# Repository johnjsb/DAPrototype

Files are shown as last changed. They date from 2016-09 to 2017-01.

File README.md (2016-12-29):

<div class="file">
  <div class="file-header">
  <div class="file-actions">

        <a class="btn-octicon tooltipped tooltipped-nw"
           href="https://windows.github.com"
           aria-label="Open this file in GitHub Desktop"
           data-ga-click="Repository, open with desktop, type:windows">
            <svg aria-hidden="true" class="octicon octicon-device-desktop" height="16" version="1.1" viewBox="0 0 16 16" width="16"><path fill-rule="evenodd" d="M15 2H1c-.55 0-1 .45-1 1v9c0 .55.45 1 1 1h5.34c-.25.61-.86 1.39-2.34 2h8c-1.48-.61-2.09-1.39-2.34-2H15c.55 0 1-.45 1-1V3c0-.55-.45-1-1-1zm0 9H1V3h14v8z"/></svg>
        </a>

        <!-- '"` --><!-- </textarea></xmp> --></option></form><form accept-charset="UTF-8" action="/nategreco/DAPrototype/edit/master/README.md" class="inline-form js-update-url-with-hash" data-form-nonce="98edccfe8496e23db9dd6daac1cc21b22fe630b1" method="post"><div style="margin:0;padding:0;display:inline"><input name="utf8" type="hidden" value="&#x2713;" /><input name="authenticity_token" type="hidden" value="Xxg+MZ2gaWbK/x79SvOasrFMR/OtOR6YhneYzXq2UvHyrXHXdxic8k2Q9TFyRKGyG20oO6GQx6e75jDCMJZNnA==" /></div>
          <button class="btn-octicon tooltipped tooltipped-nw" type="submit"
            aria-label="Fork this project and edit the file" data-hotkey="e" data-disable-with>
            <svg aria-hidden="true" class="octicon octicon-pencil" height="16" version="1.1" viewBox="0 0 14 16" width="14"><path fill-rule="evenodd" d="M0 12v3h3l8-8-3-3-8 8zm3 2H1v-2h1v1h1v1zm10.3-9.3L12 6 9 3l1.3-1.3a.996.996 0 0 1 1.41 0l1.59 1.59c.39.39.39 1.02 0 1.41z"/></svg>
          </button>
</form>        <!-- '"` --><!-- </textarea></xmp> --></option></form><form accept-charset="UTF-8" action="/nategreco/DAPrototype/delete/master/README.md" class="inline-form" data-form-nonce="98edccfe8496e23db9dd6daac1cc21b22fe630b1" method="post"><div style="margin:0;padding:0;display:inline"><input name="utf8" type="hidden" value="&#x2713;" /><input name="authenticity_token" type="hidden" value="XiElkEE2MjGLgCf0HjS3MaQ2nTFOKo5D3A2KYL0wVELzlGp2q47HpQzvzDgmg4wxDhfy+UKDV3zhnCJv9xBLLw==" /></div>
          <button class="btn-octicon btn-octicon-danger tooltipped tooltipped-nw" type="submit"
            aria-label="Fork this project and delete the file" data-disable-with>
            <svg aria-hidden="true" class="octicon octicon-trashcan" height="16" version="1.1" viewBox="0 0 12 16" width="12"><path fill-rule="evenodd" d="M11 2H9c0-.55-.45-1-1-1H5c-.55 0-1 .45-1 1H2c-.55 0-1 .45-1 1v1c0 .55.45 1 1 1v9c0 .55.45 1 1 1h7c.55 0 1-.45 1-1V5c.55 0 1-.45 1-1V3c0-.55-.45-1-1-1zm-1 12H3V5h1v8h1V5h1v8h1V5h1v8h1V5h1v9zm1-10H2V3h9v1z"/></svg>
          </button>
</form>  </div>

</div>

  <div id="readme" class="readme blob instapaper_body">
    <article class="markdown-body entry-content" itemprop="text"><h1><a id="user-content-product-name" class="anchor" href="#product-name" aria-hidden="true"><svg aria-hidden="true" class="octicon octicon-link" height="16" version="1.1" viewBox="0 0 16 16" width="16"><path fill-rule="evenodd" d="M4 9h1v1H4c-1.5 0-3-1.69-3-3.5S2.55 3 4 3h4c1.45 0 3 1.69 3 3.5 0 1.41-.91 2.72-2 3.25V8.59c.58-.45 1-1.27 1-2.09C10 5.22 8.98 4 8 4H4c-.98 0-2 1.22-2 2.5S3 9 4 9zm9-3h-1v1h1c1 0 2 1.22 2 2.5S13.98 12 13 12H9c-.98 0-2-1.22-2-2.5 0-.83.42-1.64 1-2.09V6.25c-1.09.53-2 1.84-2 3.25C6 11.31 7.55 13 9 13h4c1.45 0 3-1.69 3-3.5S14.5 6 13 6z"></path></svg></a>Raspberry Pi Driver Assist</h1>

<blockquote>
<p>A standalone driver assist unit based on Raspberry Pi hardware and OpenCV libraries</p>
</blockquote>

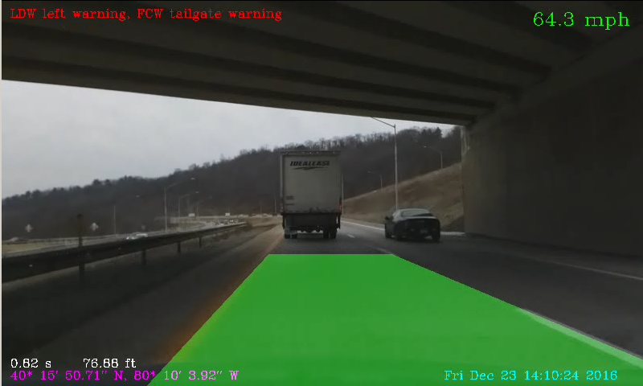
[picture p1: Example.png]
<p></p>
<p><a href="https://youtu.be/WRAR0lgYsj8">Daytime driving conditions</a></p>
<p><a href="https://youtu.be/zDFjwTFDbJ0">Nighttime driving conditions</a></p>
<p><a href="https://youtu.be/yc1ApW6gV3I">Rainy driving conditions</a></p>

<blockquote>
<p>This project is an attempt to create a standalone, windshield mounted driver assist unit with the following functionality:
<ul>
<li>LDW (Lane Departure Warning)</li>
<li>FCW (Forward Collision Warning)</li>
<li>Tailgate warning</li>
<li>Driver pull-ahead warning</li>
<li>Dashcam functionality (with GPS & timestamp overlay)</li>
</ul>
</p>
</blockquote>

<h2><a id="user-content-installation" class="anchor" href="#installation" aria-hidden="true"><svg aria-hidden="true" class="octicon octicon-link" height="16" version="1.1" viewBox="0 0 16 16" width="16"><path fill-rule="evenodd" d="M4 9h1v1H4c-1.5 0-3-1.69-3-3.5S2.55 3 4 3h4c1.45 0 3 1.69 3 3.5 0 1.41-.91 2.72-2 3.25V8.59c.58-.45 1-1.27 1-2.09C10 5.22 8.98 4 8 4H4c-.98 0-2 1.22-2 2.5S3 9 4 9zm9-3h-1v1h1c1 0 2 1.22 2 2.5S13.98 12 13 12H9c-.98 0-2-1.22-2-2.5 0-.83.42-1.64 1-2.09V6.25c-1.09.53-2 1.84-2 3.25C6 11.31 7.55 13 9 13h4c1.45 0 3-1.69 3-3.5S14.5 6 13 6z"></path></svg></a>Installation</h2>

<p>Debian (Jessie):</p>
<div class="highlight highlight-source-shell">
<pre>todo</pre>
</div>

<h2><a id="user-content-usage-example" class="anchor" href="#usage-example" aria-hidden="true"><svg aria-hidden="true" class="octicon octicon-link" height="16" version="1.1" viewBox="0 0 16 16" width="16"><path fill-rule="evenodd" d="M4 9h1v1H4c-1.5 0-3-1.69-3-3.5S2.55 3 4 3h4c1.45 0 3 1.69 3 3.5 0 1.41-.91 2.72-2 3.25V8.59c.58-.45 1-1.27 1-2.09C10 5.22 8.98 4 8 4H4c-.98 0-2 1.22-2 2.5S3 9 4 9zm9-3h-1v1h1c1 0 2 1.22 2 2.5S13.98 12 13 12H9c-.98 0-2-1.22-2-2.5 0-.83.42-1.64 1-2.09V6.25c-1.09.53-2 1.84-2 3.25C6 11.31 7.55 13 9 13h4c1.45 0 3-1.69 3-3.5S14.5 6 13 6z"></path></svg></a>Hardware</h2>

<p>Part List:</p>
<div class="highlight highlight-source-shell">
<ul>
<li>Raspberry Pi v3</li>
<li>8gb (or greater) class 10 SD card</li>
<li>Rasbperry Pi v2.1 camera with cable</li>
<li>LidarLite (v3) LIDAR rangefinder</li>
<li>Adafruit Ultimate GPS</li>
<li>GPS antenna and adapter</li>
<li>5" HDMI 800x480 screen</li>
<li>Flexible HDMI elbow</li>
<li>Buzzer</li>
<li>Female DC barrel jack connector</li>
<li>Cigarette adapter with male DC barrel connector</li>
<li>68000000uF 16V capacitor</li>
<li>Power LED</li>
<li>3D printed or other fabricated housing</li>
<li>Custom made breadboard</li>
<ul>
<li>DC:DC buck poswer supply, 12V to 5V</li>
<li>40-pin female header</li>
<li>12V relay</li>
<li>Various resistors, diodes, male and female header pins</li>
</ul>
</ul>
</div>

<h2><a id="user-content-development-setup" class="anchor" href="#development-setup" aria-hidden="true"><svg aria-hidden="true" class="octicon octicon-link" height="16" version="1.1" viewBox="0 0 16 16" width="16"><path fill-rule="evenodd" d="M4 9h1v1H4c-1.5 0-3-1.69-3-3.5S2.55 3 4 3h4c1.45 0 3 1.69 3 3.5 0 1.41-.91 2.72-2 3.25V8.59c.58-.45 1-1.27 1-2.09C10 5.22 8.98 4 8 4H4c-.98 0-2 1.22-2 2.5S3 9 4 9zm9-3h-1v1h1c1 0 2 1.22 2 2.5S13.98 12 13 12H9c-.98 0-2-1.22-2-2.5 0-.83.42-1.64 1-2.09V6.25c-1.09.53-2 1.84-2 3.25C6 11.31 7.55 13 9 13h4c1.45 0 3-1.69 3-3.5S14.5 6 13 6z"></path></svg></a>Third party libraries</h2>

<p>Requirements:</p>
<div class="highlight highlight-source-shell">
<ul>
<li>OpenCv 3.1.0</li>
<li>Raspicam 0.1.3</li>
<li>WiringPi 2.29</li>
</ul>
</div>

<h2><a id="user-content-release-history" class="anchor" href="#release-history" aria-hidden="true"><svg aria-hidden="true" class="octicon octicon-link" height="16" version="1.1" viewBox="0 0 16 16" width="16"><path fill-rule="evenodd" d="M4 9h1v1H4c-1.5 0-3-1.69-3-3.5S2.55 3 4 3h4c1.45 0 3 1.69 3 3.5 0 1.41-.91 2.72-2 3.25V8.59c.58-.45 1-1.27 1-2.09C10 5.22 8.98 4 8 4H4c-.98 0-2 1.22-2 2.5S3 9 4 9zm9-3h-1v1h1c1 0 2 1.22 2 2.5S13.98 12 13 12H9c-.98 0-2-1.22-2-2.5 0-.83.42-1.64 1-2.09V6.25c-1.09.53-2 1.84-2 3.25C6 11.31 7.55 13 9 13h4c1.45 0 3-1.69 3-3.5S14.5 6 13 6z"></path></svg></a>Release History</h2>

<ul>
<li>0.0.1

<ul>
<li>Work in progress</li>
</ul></li>
</ul>

<h2><a id="user-content-meta" class="anchor" href="#meta" aria-hidden="true"><svg aria-hidden="true" class="octicon octicon-link" height="16" version="1.1" viewBox="0 0 16 16" width="16"><path fill-rule="evenodd" d="M4 9h1v1H4c-1.5 0-3-1.69-3-3.5S2.55 3 4 3h4c1.45 0 3 1.69 3 3.5 0 1.41-.91 2.72-2 3.25V8.59c.58-.45 1-1.27 1-2.09C10 5.22 8.98 4 8 4H4c-.98 0-2 1.22-2 2.5S3 9 4 9zm9-3h-1v1h1c1 0 2 1.22 2 2.5S13.98 12 13 12H9c-.98 0-2-1.22-2-2.5 0-.83.42-1.64 1-2.09V6.25c-1.09.53-2 1.84-2 3.25C6 11.31 7.55 13 9 13h4c1.45 0 3-1.69 3-3.5S14.5 6 13 6z"></path></svg></a>Meta</h2>

<p>Nathan Greco – <a href="https://www.linkedin.com/in/nathan-greco-8050b210">LinkedIn</a> – <a href="mailto:nathan.greco@gmail.com">Nathan.Greco@gmail.com</a></p>

<p>Distributed under the GNU GPL 3.0 license. See <code>LICENSE</code> for more information.</p>

<p><a href="https://github.com/nategreco/">https://github.com/nategreco/github-link</a></p>
</article>
  </div>

</div>

<div id="jump-to-line" style="display:none">
  <!-- '"` --><!-- </textarea></xmp> --></option></form><form accept-charset="UTF-8" action="" class="js-jump-to-line-form" method="get"><div style="margin:0;padding:0;display:inline"><input name="utf8" type="hidden" value="&#x2713;" /></div>
    <input class="form-control linejump-input js-jump-to-line-field" type="text" placeholder="Jump to line&hellip;" aria-label="Jump to line" autofocus>
</form></div>

  </div>
  
</div>

  <div class="site-footer" role="contentinfo">
    <ul class="site-footer-links float-right">
        <li><a href="https://github.com/contact" data-ga-click="Footer, go to contact, text:contact">Contact GitHub</a></li>
      <li><a href="https://developer.github.com" data-ga-click="Footer, go to api, text:api">API</a></li>
      <li><a href="https://training.github.com" data-ga-click="Footer, go to training, text:training">Training</a></li>
      <li><a href="https://shop.github.com" data-ga-click="Footer, go to shop, text:shop">Shop</a></li>
        <li><a href="https://github.com/blog" data-ga-click="Footer, go to blog, text:blog">Blog</a></li>
        <li><a href="https://github.com/about" data-ga-click="Footer, go to about, text:about">About</a></li>

 </a>
    <ul class="site-footer-links">
      <li>&copy; 2016 <span title="0.09722s from github-fe-1e914f7.cp1-iad.github.net">GitHub</span>, Inc.</li>
        <li><a href="https://github.com/site/terms" data-ga-click="Footer, go to terms, text:terms">Terms</a></li>
        <li><a href="https://github.com/site/privacy" data-ga-click="Footer, go to privacy, text:privacy">Privacy</a></li>
        <li><a href="https://github.com/security" data-ga-click="Footer, go to security, text:security">Security</a></li>
        <li><a href="https://status.github.com/" data-ga-click="Footer, go to status, text:status">Status</a></li>
        <li><a href="https://help.github.com" data-ga-click="Footer, go to help, text:help">Help</a></li>
    </ul>
  </div>
</div>

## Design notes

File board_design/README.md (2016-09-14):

This folder will the circuit board design for for the driver assist device.

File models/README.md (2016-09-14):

This folder will the 3D models for the housing of the driver assist device.

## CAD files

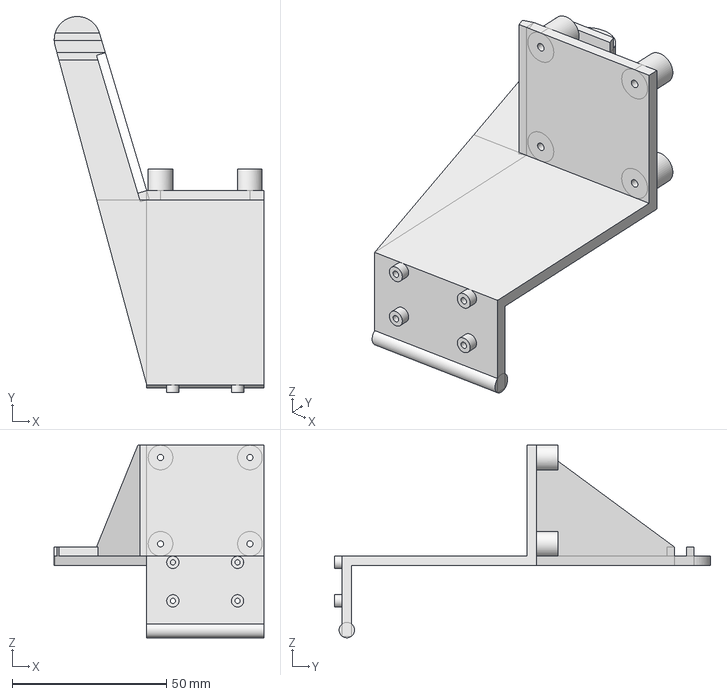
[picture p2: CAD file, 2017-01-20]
models/DAPrototypeInset.FCStd
68.0 x 122.0 x 62.5 mm

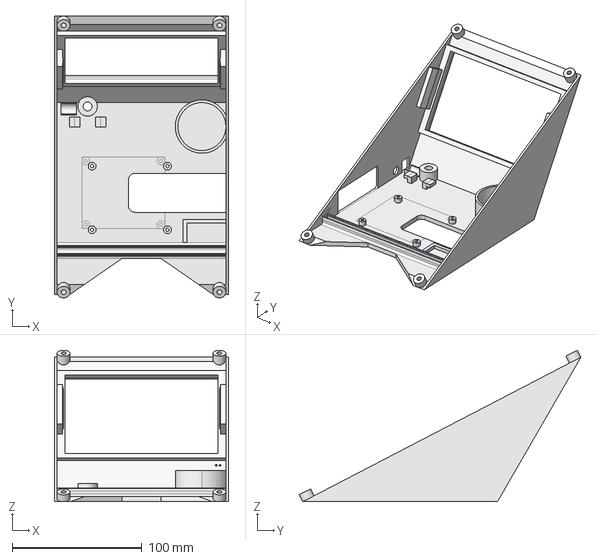
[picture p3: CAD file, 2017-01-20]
models/DAPrototypeHolder.FCStd
134.0 x 217.1 x 116.7 mm

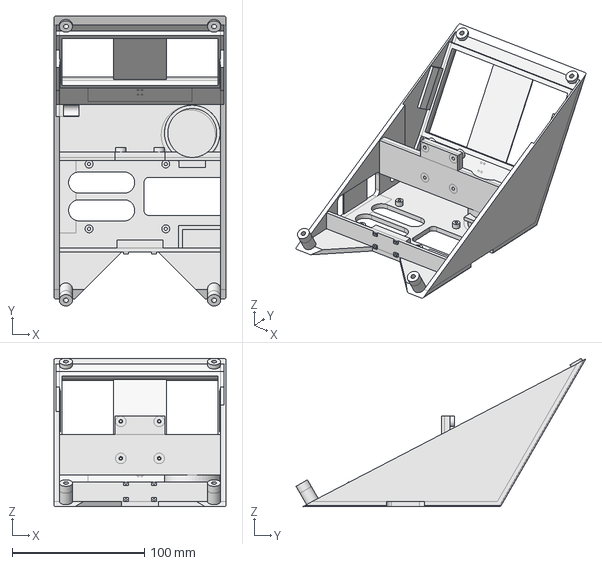
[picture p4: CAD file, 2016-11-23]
models/DAPrototypeV5.FCStd
130.0 x 219.3 x 112.2 mm

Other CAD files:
models/DAPrototypeHolder.stl
models/DAPrototypeInset.stl
models/DAprototypeV5.stl

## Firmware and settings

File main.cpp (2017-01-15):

/******************************************************************************************
  Date:    12.08.2016
  Author:  Nathan Greco (Nathan.Greco@gmail.com)

  Project:
      DAPrototype: Driver Assist Prototype
	  http://github.com/NateGreco/DAPrototype.git

  Description:
      This project is an attempt to create a standalone, windshield mounted driver assist
      unit with the following functionality:
		  - LDW (Lane Departure Warning)
		  - FCW (Forward Collision Warning)
		  - Tailgate warning
		  - Driver pull-ahead warning
		  - Dashcam functionality (with GPS & timestamp overlay)

  Target Hardware:
      - Raspberry Pi (v3)
	  - RPi (v2.1) 8MP camera
	  - LidarLite (v3) LIDAR rangefinder
      - Adafruit Ultimate GPS
      - HDMI screen (800x480)
	  - Custom built HAT w/ power loss GPIO and capacitors to delay power off

  Target Software platform:
      Debian disto (DietPi) running LDXE, with below libraries installed

  3rd Party Libraries:
      - OpenCV 3.1.0		-> http://www.opencv.org *Compiled with OpenGL support
      - Raspicam 0.1.3		-> http://www.uco.es/investiga/grupos/ava/node/40
	  - WiringPi 2.29		-> http://wiringpi.com/
	  
  License:
	  This software is licensed under GNU GPL v3.0

  History:
      Date         Author      Description
-------------------------------------------------------------------------------------------
      12.08.2016   N. Greco    Initial creation
      07.09.2016   N. Greco    GIT repository created
	  04.10.2016   N. Greco    Compiled and tested on raspberry pi hardware
******************************************************************************************/


//Standard libraries
#include <iostream>
#include <algorithm>
#include <fstream>
#include <string>
#include <thread>
#include <cstdlib>
#include <mutex>
#include <atomic>

//3rd party libraries
#include "opencv2/opencv.hpp"
#include <libgpsmm.h>

//DAPrototype source files
#include "display_handler.h"
#include "gpio_handler.h"
#include "gps_polling.h"
#include "image_capturer.h"
#include "image_editor.h"
#include "image_processor.h"
#include "lane_detect_processor.h"
#include "lidar_polling.h"
#include "pace_setter_class.h"
#include "process_values_class.h"
#include "video_writer.h"
#include "xml_reader.h"
#include "fcw_tracker_class.h"

void PrintHeader ()
{
	time_t t = time(0);
    struct tm * now = localtime( & t );
    std::cout << '\n';
    std::cout << "Program launched at: ";
    std::cout << (now->tm_year + 1900) << '-' 
			  << (now->tm_mon + 1) << '-'
			  <<  now->tm_mday
			  << '\n' << '\n';
}

int main()
{
	std::cout << "Program launched, starting log file..." << '\n';
	//Quick and dirty log file
	std::ofstream out("/log.txt", std::ios_base::app | std::ios_base::out);
	std::streambuf *coutbuf = std::cout.rdbuf();
	std::cout.rdbuf(out.rdbuf());
	
	//Create log header
	PrintHeader();
	
    //Check XML Properties
	if (settings::kreadsuccess < 0) {
        std::cout << "XML reading failed, using defaults." << '\n';
    } else {
        std::cout << "XML reading successful!" << '\n';
    }

	//Create shared resources
	std::atomic<bool> exitsignal{ false };
    cv::Mat captureimage;
	std::mutex capturemutex;
	cv::Mat displayimage;
	std::mutex displaymutex;
	ProcessValues processvalues;
	
	//Start threads

	//Start image capture thread
    std::thread t_imagecapture( CaptureImageThread,
	                            &captureimage,
								&capturemutex,
								&exitsignal );
	//Start image processor thread
    std::thread t_imageprocessor( ProcessImageThread,
								  &captureimage,
								  &capturemutex,
								  &processvalues,
								  &exitsignal );
	//Start display thread
	std::thread t_displayupdate( DisplayUpdateThread,
								 &displayimage,
								 &displaymutex,
								 &exitsignal );
	//Start image editor thread
    std::thread t_imeageeditor( ImageEditorThread,
								&captureimage,
								&capturemutex,
								&displayimage,
								&displaymutex,
								&processvalues,
								&exitsignal );
	//Start video writer thread
    std::thread t_videowriter( VideoWriterThread,
							   &captureimage,
							   &capturemutex,
							   &displayimage,
							   &displaymutex,
							   &exitsignal );

    //Set pace setter class!
	int pollrate{ std::max(std::max(settings::comm::kpollrategps,
									settings::comm::kpollratelidar),
						   settings::comm::kpollrategpio) };
	int bufferflushrate { pollrate * 10};	//Every 10 seconds
	int gpspollinterval{ pollrate / settings::comm::kpollrategps };
	int gpiopollinterval{ pollrate / settings::comm::kpollrategpio };
	int fcwpollinterval{ pollrate / settings::comm::kpollratelidar };
	PaceSetter mypacesetter( pollrate, "Main" );
	
	//Setup polling

	//GPIO
	bool gpiopoll{ false };
	if ( settings::gpio::kenabled ) {
		try {
			gpiopoll = GpioHandlerSetup();
		} catch ( const std::exception& ex ) {
			std::cout << "GPIO handler setup threw exception: "<< ex.what() << '\n';
			gpiopoll = false;
		} catch ( const std::string& str ) {
			std::cout << "GPIO handler setup threw exception: "<< str << '\n';
			gpiopoll = false;
		} catch (...) {
			std::cout << "GPIO handler setup threw exception of unknown type!" << '\n';
			gpiopoll = false;
		}
	}
	//GPS
	gpsmm* gpsrecv{ NULL };
	bool gpspoll{ false };
	bool timeset{ false };
	if ( settings::gps::kenabled ) {
		try {
			gpsrecv = new gpsmm("localhost", DEFAULT_GPSD_PORT);
			gpspoll = GpsPollingSetup( gpsrecv );
		} catch ( const std::exception& ex ) {
			std::cout << "GPS polling setup threw exception: "<< ex.what() << '\n';
			gpspoll = false;
		} catch ( const std::string& str ) {
			std::cout << "GPS polling setup threw exception: "<< str << '\n';
			gpspoll = false;
		} catch (...) {
			std::cout << "GPS polling setup threw exception of unknown type!" << '\n';
			gpspoll = false;
		}
	} else {
		gpsrecv = NULL;
	}
	//FCW
	FcwTracker* fcwtracker{ NULL };
	bool fcwpoll{ false };
	int dacmodule{ -1 };
	if ( settings::fcw::kenabled ) {
		try {
			fcwtracker = new FcwTracker( settings::fcw::ksamplestoaverage );
			dacmodule = LidarPollingSetup();
			if ( dacmodule >= 0 ) fcwpoll = true;
		} catch ( const std::exception& ex ) {
			std::cout << "FCW setup threw exception: "<< ex.what() << '\n';
			fcwpoll = false;
		} catch ( const std::string& str ) {
			std::cout << "FCW setup threw exception: "<< str << '\n';
			fcwpoll = false;
		} catch (...) {
			std::cout << "FCW setup threw exception of unknown type!" << '\n';
			fcwpoll = false;
		}
	} else {
		fcwtracker = NULL;
	}
    
	//Loop
	int i{ 0 };
	do {
		//Increment
		i++;
		//Flush cout buffer every second
		if ( i % bufferflushrate == 0 ) std::cout << std::flush;
		if ( (gpspoll) &&
			 (i % gpspollinterval == 0) ) GpsPolling( processvalues,
													  gpsrecv,
													  timeset );
		if ( (gpiopoll) &&
			 (i % gpiopollinterval == 0) ) GpioHandler( processvalues,
														exitsignal );
		if ( (fcwpoll) &&
			 (i % fcwpollinterval == 0) ) LidarPolling( processvalues,
														dacmodule,
													    fcwtracker );

		//Set Pace
		mypacesetter.SetPace();
	} while( !exitsignal );
	
	//Cleanup variables
	delete gpsrecv;
	gpsrecv = NULL;
	delete fcwtracker;
	fcwtracker = NULL;

    //Handle all the threads
	t_videowriter.join();
	t_imageprocessor.join();
	t_imeageeditor.join();
	t_imagecapture.join();
	t_displayupdate.join();

	//Flush buffer and close file
	std::cout << std::flush;
	std::cout.rdbuf(coutbuf);
	std::cout << "Program exited gracefully!"  << '\n';

    return 0;
}

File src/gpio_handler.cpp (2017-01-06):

/******************************************************************************************
  Date:    12.08.2016
  Author:  Nathan Greco (Nathan.Greco@gmail.com)

  Project:
      DAPrototype: Driver Assist Prototype
	  http://github.com/NateGreco/DAPrototype.git

  License:
	  This software is licensed under GNU GPL v3.0
	  
******************************************************************************************/
//Standard libraries
#include <iostream>
#include <atomic>
#include <stdlib.h>
#include <exception>
#include <string>

//3rd party libraries
#include <wiringPi.h>
#include <wiringPiI2C.h>

//Project libraries
#include "pace_setter_class.h"
#include "process_values_class.h"
#include "xml_reader.h"

//Preprocessor

//Physical pin numbers
#define BUZZERPIN 27
#define POWERINPUTPIN 4
#define POWEROUTPUTPIN 5
#define LEFTALARMPIN 17
#define LEFTWARNINGPIN 13
#define LEFTOKPIN 12
#define RIGHTALARMPIN 23
#define RIGHTWARNINGPIN 22
#define RIGHTOKPIN 18
#define FORWARDALARMPIN 26
#define FORWARDWARNINGPIN 25
#define FORWARDOKPIN 24
#define CENTERPIN 37

/*****************************************************************************************/
bool GpioHandlerSetup()
{
	//Setup GPIO pins
	wiringPiSetupGpio();
	pinMode(POWERINPUTPIN, INPUT); 
	pinMode(BUZZERPIN, OUTPUT);
	pinMode(LEFTALARMPIN, PWM_OUTPUT);
	pinMode(LEFTWARNINGPIN, PWM_OUTPUT);
	pinMode(LEFTOKPIN, PWM_OUTPUT);
	pinMode(RIGHTALARMPIN, PWM_OUTPUT);
	pinMode(RIGHTWARNINGPIN, PWM_OUTPUT);
	pinMode(RIGHTOKPIN, PWM_OUTPUT);
	pinMode(FORWARDALARMPIN, PWM_OUTPUT);
	pinMode(FORWARDWARNINGPIN, PWM_OUTPUT);
	pinMode(FORWARDOKPIN, PWM_OUTPUT);
	pinMode(CENTERPIN, OUTPUT);
	pinMode(POWEROUTPUTPIN, OUTPUT);
	digitalWrite(POWEROUTPUTPIN, 1);
	
	return true;
}

void GpioHandler( ProcessValues& processvalues,
				  std::atomic<bool>& exitsignal )
{
	try {
		//Create thread variables
		bool warning{ false };
		bool alarm{ false };
		int buzzerinterval{  settings::comm::kpollrategpio / 2  };	//500ms
		int blinkinterval{  settings::comm::kpollrategpio / 2  };	//500ms
		int buzzercount{ 0 };
		int blinkercount{ 0 };
		int inputfailcount{ 0 };
		
		//Check for Warnings
		if ( (processvalues.ldwstatus_ > LDW_RIGHT_DEVIATION_OK) ||
			 (processvalues.fcwstatus_ > FCW_ACTIVE) ||
			 (processvalues.gpsstatus_ > GPS_LOCK_LDW_ON) ) {
			warning = true;
		} else {
			warning = alarm = false;
		}
		//Check for Alarms
		if ( (processvalues.ldwstatus_ > LDW_RIGHT_DEVIATION_WARNING) ||
			 (processvalues.fcwstatus_ > FCW_TAILGATE_WARNING) ||
			 (processvalues.gpsstatus_ > GPS_SPEED_WARNING) ) {
			alarm = true;
		}

		//Shutdown logic on power loss
		if ( !digitalRead(POWERINPUTPIN) ) {
			exitsignal = true;
			std::cout << "Power loss detected, exiting!" << '\n';
			if ( settings::gpio::kautoshutdown ) {
				digitalWrite(POWEROUTPUTPIN, 0);
			}
			return;
		}

		//Set buzzer
		if ( alarm && settings::gen::kenbuzzer ) {
			digitalWrite(BUZZERPIN, 1);
		} else if ( !alarm && warning && settings::gen::kenbuzzer ) {
			buzzercount++;
			if ( buzzercount % buzzerinterval != 0) {
				//Do nothing
			} else if (digitalRead(BUZZERPIN)) {
				digitalWrite(BUZZERPIN, 1);
			} else {
				digitalWrite(BUZZERPIN, 0);
			}
		} else {
			digitalWrite(BUZZERPIN, 0);
			buzzercount = buzzerinterval - 1;
		}

		//Set center LED
		if ( (processvalues.ldwstatus_ >= LDW_INACTIVE) &&
			 (processvalues.fcwstatus_ >= FCW_ACTIVE) &&
			 (processvalues.gpsstatus_ > GPS_NO_LOCK) ) {
				digitalWrite(CENTERPIN, 1);
		} else if ( (processvalues.ldwstatus_ >= LDW_INACTIVE) &&
					(processvalues.fcwstatus_ >= FCW_ACTIVE) &&
					(processvalues.gpsstatus_ == GPS_INACTIVE) ) {
			blinkercount++;
			if ( blinkercount % blinkinterval != 0) {
				//Do nothing
			} else if (digitalRead(CENTERPIN)) {
				digitalWrite(CENTERPIN, 1);
			} else {
				digitalWrite(CENTERPIN, 0);
			}
			} else {
			digitalWrite(CENTERPIN, 0);
		}
	} catch ( const std::exception& ex ) {
		std::cout << "GPIO handler thread threw exception: "<< ex.what() << '\n';
	} catch ( const std::string& str ) {
		std::cout << "GPIO handler thread threw exception: "<< str << '\n';
	} catch (...) {
		std::cout << "GPIO handler thread threw exception of unknown type!" << '\n';
	}
	
	return;
}

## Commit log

2016-09-14 Added directories for models and circuit design
2016-09-14 Updated gpio and corrected mistake in gps
    [gpio_handler.cpp]
2016-09-14 Wrote PWM logic for LEDs
2016-09-14 Created driver pullahead warning
2016-09-16 Added comments to consider HoughLinesP instead of findContours, as well as comment to implmenet road angle as a fudge factor for FCW in lidar polling, and finally created a GPS average function
2016-09-17 Added freecad and stl models for case.
    [DAPrototypeV1.FCStd, DAprototypeV1.stl]
2016-09-19 Added freecad models
    [DAPrototypeV2.FCStd, DAprototypeV2.stl]
2016-09-21 Added v2 models
    [DAPrototypeV2.FCStd, DAprototypeV2.stl]
2016-09-23 Moved over changes from learning program, which included some corrections to contour pairing scoring function and also abandoned blob detection methods
    [DAPrototypeV2.FCStd, DAprototypeV2.stl]
2016-09-27 Added v4 of modeol
    [DAPrototypeV2.FCStd, DAPrototypeV2old.FCStd, DAPrototypeV3.FCStd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]
2016-09-27 Removed older model files
    [DAPrototypeV1.FCStd, DAPrototypeV2.FCStd, DAPrototypeV2old.FCStd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]
2016-10-04 Corrected resizing of both recorded and displayed image, also added preprocessor macro for compiling on raspberry pi
2016-10-04 Added preprocessor instructions for compiling on raspberry pi
2016-10-05 Now compiles, links, and runs, on RPi w/ WiringPi libraries and imshow with OpenGL option
2016-10-05 Added RPI target compile flag and multi-threading during build
2016-10-15 Exit immediately if powered off
2016-10-16 Corrected std::fpclassify function to compare to enum FP_NORMAL so findpolygon function works on both linux and windows
    [main.cpp]
2016-10-16 Switched back to logging in a text file
2016-10-16 Removed division by literals to improve ARM performance
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2016-10-30 Updated lidar polling for requesting read and constructing result
    [DAPrototypeV4.FCStd]
2016-10-30 added debugging print out
2016-11-04 Added filter for common angle deviation from center to make sure lines are mirros
2016-11-04 Added libraries for lidarlite
2016-11-08 Trying different PMTK commands to change sample rate to 5 hz
2016-11-08 Removed std::endl and replaced with 'n'
    [gpio_handler.cpp, lidar_polling.cpp]
2016-11-08 Mistake, 'n' should have been '\n'
    [gpio_handler.cpp, lidar_polling.cpp]
2016-11-09 Created handshake between frame queue, storage worker, and the video writer thread when releasing and renaming files
2016-11-09 Setup handling of lidar read failures
    [lidar_polling.cpp]
2016-11-09 Corrected velocity/accel calculation
2016-11-09 Adjusted filter for timetocollision
2016-11-09 Changed percent deviation based off of current road width
2016-11-10 Copied corrections of minimum angle filter and removed fitline function in contour evaluation for improved performance (using ellipse angle now)
    [lidar_polling.cpp]
2016-11-12 Corrected common angle filtering and updated formatting
2016-11-12 Corrected common lane angle filtering (again)
2016-11-16 Moved pace setter initialization before first while loops in threads
2016-11-17 Updated mask read errors less than 500 ms
    [lidar_polling.cpp]
2016-11-21 Changed while loop so ESC exits program
2016-11-22 Removed pwm member variables
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2016-11-23 Updated model to vent some heat off Pi and abandoned front LED's except power
    [DAPrototypeV5.FCStd, DAprototypeV5.stl]
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2016-11-23 Corrected class contructor to remove distanceoffset
    [lidar_polling.cpp]
2016-11-23 Brought back fitline and tightened common angle window
2016-11-24 Correct missing unit conversion when evaluating result
    [lidar_polling.cpp]
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2016-11-30 Changed slope in FindPolygon to inverse to improve performance on ARM platform
2016-12-02 Had to remove score from print lines function
2016-12-03 Added script files and locations in a readme file
    [config.txt]
2016-12-07 Implemented contour filtering by angle diffference to vanishing point
2016-12-07 Corrected angle filtering with sorting of contours, also removed commented logic
2016-12-08 Difference from center filtering removed now that the vanishingpoint angle is considered
2016-12-11 By using only one gps structure, crashing the gps thread is avoided
2016-12-11 Changed so thread wouldn't attempt to sleep a negative time length
2016-12-11 Removed older models
    [DAPrototypeV4.FCStd, DAprototypeV4.stl]
2016-12-20 Eliminated preprocessor if/then/else so compiles on raspberry pi only
2016-12-21 Added handling of bad lidar comms, where returned value is ushort_max
2016-12-27 Started new model with FreeCAD 0.16, old one has too many errors
    [DAPrototype.FCStd]
2016-12-27 Added generic error hangling for each thread loop, needs tested
    [gpio_handler.cpp, lidar_polling.cpp]
2016-12-27 Changed model to two-piece design so angle of camera and lidar can be adjustable by thumbscrew
    [DAPrototype.FCStd, DAPrototypeHolder.FCStd, DAPrototypeInset.FCStd]
2016-12-27 Created pivot point for camera/lidar shelf
    [DAPrototypeHolder.FCStd, DAPrototypeInset.FCStd]
2016-12-27 Corrected string exception hangling
    [gpio_handler.cpp, lidar_polling.cpp]
2016-12-28 Corrected if then statement for following distance so alarm can occur
    [lidar_polling.cpp]
2016-12-28 Created opening for LCD
    [DAPrototypeHolder.FCStd]
2016-12-28 Added mounts and cutouts for Raspberry Pi Board
    [DAPrototypeHolder.FCStd]
2016-12-28 Added holes for barrel connector and GPS connector
    [DAPrototypeHolder.FCStd]
2016-12-28 Added hole for Power LED
    [DAPrototypeHolder.FCStd]
2016-12-28 Added capacitor holder
    [DAPrototypeHolder.FCStd]
2016-12-28 Added boss for 3/8'' thumbscrew for angle adjustment
    [DAPrototypeHolder.FCStd]
2016-12-28 Moved thumbscrew boss back and created opening for camera
    [DAPrototypeHolder.FCStd]
2016-12-28 Added stl of holder
    [DAPrototypeHolder.stl]
2016-12-28 Added hooks for a rubber band to hold down insert, however the insert is now a wierd lookin thing that can't be printed easily
    [DAPrototypeHolder.FCStd, DAPrototypeHolder.stl, DAPrototypeInset.FCStd]
2016-12-29 Made insert easier to print and also added edges for rubber band to catch
    [DAPrototypeInsert.stl, DAPrototypeInset.FCStd]
2016-12-31 Re-made inset to be taller and hav correct positioning of thumb-screw contacdt
    [DAPrototypeInsert.stl, DAPrototypeInset.FCStd, DAPrototypeInset.stl]
2017-01-01 Changed polling threads to functions and inserted into main loop
2017-01-02 Added more support for inset
    [DAPrototypeInset.FCStd, DAPrototypeInset.stl]
2017-01-02 Changed diameter of thumbscrew hole and added spot for buzzer
    [DAPrototypeHolder.FCStd, DAPrototypeHolder.stl]
2017-01-03 Corrected inappropriate use of continue statement to exit if state and changed -> operator to .
    [gpio_handler.cpp, lidar_polling.cpp]
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2017-01-04 Updated alarm and warning limits to match 2017 Camry Driver Assist
2017-01-05 GPS works, however program doesn't exit
    [gpio_handler.cpp, main.cpp]
2017-01-06 Was forced to create new sketches and pads to thicken each side 0.5mm
    [DAPrototypeHolder.FCStd]
2017-01-06 Various formatting and changed lidar polling to pass fcwtracker by pointer
2017-01-06 Rearranged GPIO catch statements to be consistent with gps and lidar polling
2017-01-06 Readded model from master branch
    [DAPrototypeHolder.FCStd]
2017-01-09 Fixed repeated settime locking up polling functions
    [main.cpp]
2017-01-14 Corrected std::flush of std::cout to every 10 seconds to prevent slowing down main polling loop
    [main.cpp]
2017-01-20 Moved files from AddGpsThread
    [DAPrototypeHolder.FCStd, DAPrototypeHolder.stl]
2017-01-20 Trimmed overhang to make completely flat face
    [DAPrototypeInset.FCStd, DAPrototypeInset.stl]
2017-01-20 Rotated for optimal printing
    [DAPrototypeHolder.stl, DAPrototypeInset.stl]
